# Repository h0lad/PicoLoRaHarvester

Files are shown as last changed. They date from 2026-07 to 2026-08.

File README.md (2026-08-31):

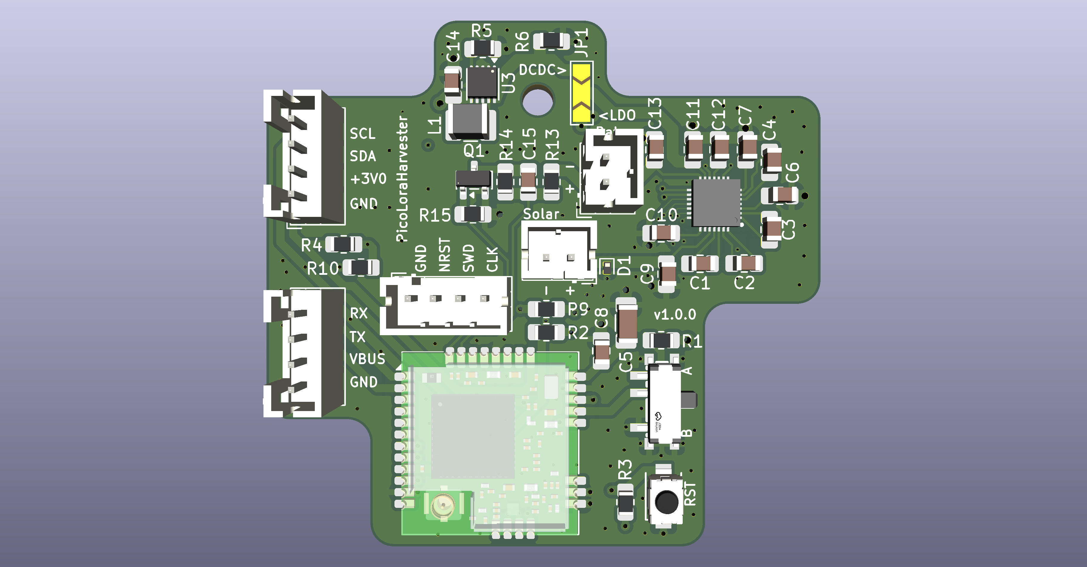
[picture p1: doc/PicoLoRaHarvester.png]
MeshtasticRouterNode


# PicoLoRaHarvester

## What is this thing?

This PCB integrates a [RAK3172 LoRa module](https://docs.rakwireless.com/Product-Categories/WisDuo/RAK3172-Module/Datasheet/) (STM32WLE5) with a [Nexperia NEH7100](https://assets.nexperia.com/documents/data-sheet/NEH7100.pdf) energy harvesting PMIC. 

Main target are solar-powered LoRa nodes that run unattended in off-grid locations.

The board is compatible to Meshcore and Mesthastic. But basically it's a nice platform for all kind of LoRa(WAN) applications.

Beware that both firmwares need Power Saving patches (Semtech RX duty cycle and uC deep sleep) due to the limited harvesting capability of the IC.

For get the basic device running you only have to populate the NEF7100 + Voltage Divider with Mosfet + RAK3172 + Switch + SWD. All others (FRAM/DCDC) is optional. This should make it by far the cheapest Meshcore repeater in the market.

## Features

* Energy harvesting via Nexperia NEH7100 PMIC: 15 μW to 100 mW input range, up to 95% efficiency
* Compatible to basically all all 1-cell energy storage: LiPo, LiFePo4, LTO, Supercaps, etc.
* Storage Type, OVP/UVP/etc. can be configured with solder bridges on the back
* With a soldering bridge you can either go for the internal Nexperia NEH7100 LDO (for low BOM) or use a TI TPS63900 Buck-Boost Converter
* USB bypass charging (VUSB) at up to 200 mA via the UART connector
* Battery (ADC_LIPO) voltage monitoring using a voltage divider, on/off switchable with a n-Mosfet
* I²C Infineon FRAM (FM24V10) on the back for data logging 

## Physical Outlines

| Dimension | Value |
|---|---|
| Width | 50.54 mm |
| Height | 45.50 mm |

Fits into this box: [Aliexpress, F-type, 63x58x35](https://de.aliexpress.com/item/1005005480970197.html).

Yes - the mounting hole is not symmetric. 

## Pinout

### Connectors

| Designator | Connector | Pins | Purpose |
|---|---|---|---|
| J1 | Pin header 1x06 (1.00 mm) | 1: GND, 2: +3V0, 3: SPI1 SS (PA4), 4: SPI1 CLK (PA5), 5: SPI1 MISO (PA6), 6: SPI1 MOSI (PA7) | SPI expansion bus (SPI1) |
| J2 | JST PH 2-pin | 1: VBUS, 2: GND | Solar panel input (feeds NEH7100 energy harvester) |
| J3 | JST PH 4-pin | 1: GND, 2: VUSB, 3: UART TX, 4: UART RX | UART + USB bypass charging (200 mA) |
| J4 | JST PH 2-pin | 1: VLIPO, 2: GND | LiPo battery |
| J5 | JST PH 4-pin | 1: GND, 2: +3V0, 3: I2C1 SDA, 4: I2C1 SCL | I²C expansion bus (I2C1) |
| J6 | JST PH 4-pin | 1: GND, 2: NRST, 3: SWD, 4: SWCLK | SWD debug/programming |

### RAK3172 Pin Mapping

| RAK3172 Pin | Function | Connected To |
|---|---|---|
| PA2 | UART2 TX | J3 pin 3 |
| PA3 | UART2 RX | J3 pin 4 |
| PA4 | SPI1 SS | J1 pin 3 |
| PA5 | SPI1 CLK | J1 pin 4 |
| PA6 | SPI1 MISO | J1 pin 5 |
| PA7 | SPI1 MOSI | J1 pin 6 |
| PA9 | I2C1 SCL | J5 pin 4, U4 (FM24V10) SCL |
| PA10 | I2C1 SDA | J5 pin 3, U4 (FM24V10) SDA |
| PA11 | I2C2 SDA | NEH7100 SDA (PMIC config bus) |
| PA12 | I2C2 SCL | NEH7100 SCL (PMIC config bus) |
| PA13 | SWDIO | J6 pin 3 |
| PA14 | SWCLK | J6 pin 4 |
| PB3 / A0 | GPIO out | EN_VOL_DIVIDER (Q1 n-MOSFET load switch for the ADC_LIPO divider) |
| PB4 / A1 | ADC | ADC_LIPO (battery voltage divider, R13/R14 + C15) |
| BOOT0 | Bootloader | SW1 (SSSS811101 slide switch) via R1 (10 kΩ) |
| NRST | Reset | SW2 (push button), J6 pin 2 |

### I²C Bus Allocation

| Bus | Pins | Purpose |
|-----|---|---|
| I2C1 | PA9 (SCL), PA10 (SDA) | J5 expansion connector for external sensors/peripherals + FM24V10 F-RAM (U4, on the back) for data logging |
| I2C2 | PA12 (SCL), PA11 (SDA) | NEH7100 PMIC telemetry and configuration |

Both I²C buses have on-board 10 kΩ pull-up resistors (R4/R10 for I2C1, R2/R9 for I2C2).

## Voltage Monitoring

| Net | Divider | Ratio | RAK3172 ADC Pin |
|-----|---|---|---|
| ADC_LIPO | R13 (390 kΩ) / R14 (1 MΩ) + C15 (100 nF) | ~0.72 | PB4 / A1 |

## FAQ

#### How much current can I expect from the NEH7100?

The NEH7100 has an input power range of 15 μW to 100 mW and efficiency up to 95% (per [datasheet](https://assets.nexperia.com/documents/data-sheet/NEH7100.pdf)).

The USB input (VUSB on J3 pin 2) bypasses the charge pump and can supply up to 200 mA directly for bench use or supplemental charging.

#### Why the NEH7100 instead of the TI BQ25570?

* Voltage thresholds (OVP, LVD, LDO) are set by hard-code pins or I²C registers. The BQ25570 programs them with external resistor dividers, which adds resistor tolerance to every threshold and a permanent leakage path across the battery.
* The charge current can be read back over I²C (I_MEASURED/I_RANGE registers). The BQ25570 has no digital interface.
* External circuit consists of capacitors only. The BQ25570 needs an inductor each for its boost charger and buck converter.
* The pinout groups the flying caps, I²C and power pins by side, so routing needs no crossovers and there are no switching inductor loops to keep tight.

## Hardware Verification

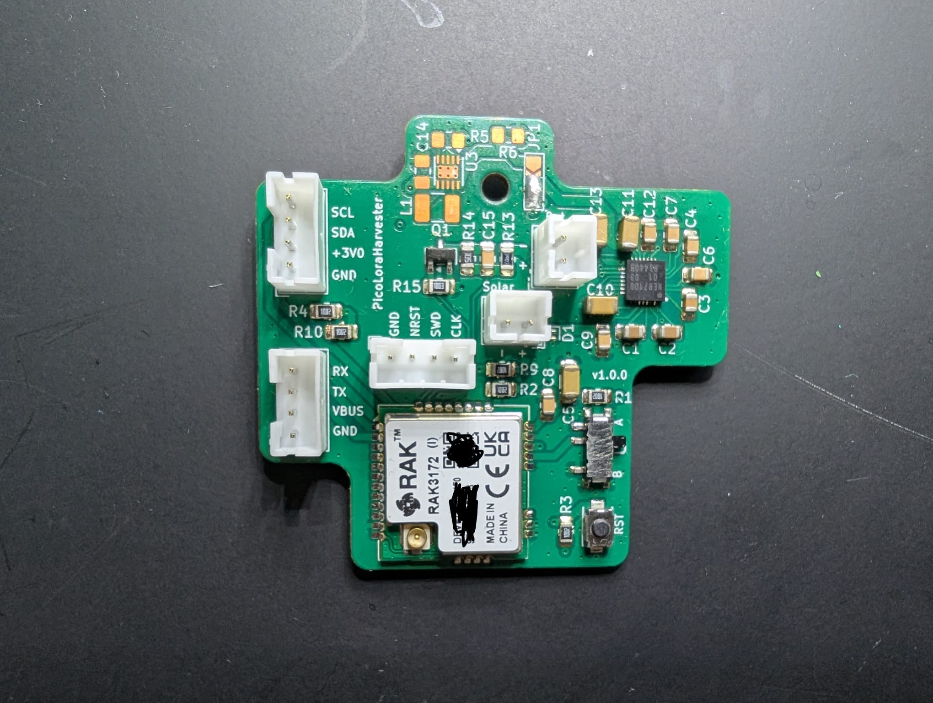
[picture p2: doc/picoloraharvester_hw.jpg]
PicoLoRaHarvester


✅ HC 00001 Configuration works

✅ Bat -> 3.0V via LDO

✅ Charging Bat via VIN

## License

CERN-OHL-S-2.0

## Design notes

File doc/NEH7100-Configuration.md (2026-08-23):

## NEH7100 without LDO/Buck → STM32WLE

This uses the wide voltage input range of the STM32WLE. It perfectly fits a LiFePO4.

LDO in bypass: `VLDO` follows `VBAT`.

| Chemistry | Climate | HC\[4:0\] | HC live (OVP / LVD / USB) | `0x00` | `0x01` | `0x05` |
|---|---|---|---|---|---|---|
| LiFePO4 | mountain | `11010` | 3.50 / 2.50 / 150 mA | `0x65` 2.80 / 3.50 | `0x87` | `0x00` |
| LiFePO4 | indoor | `11010` | 3.50 / 2.50 / 150 mA | `0x36` 2.50 / 3.60 | `0x87` | `0x01` |

## NEH7100 with a connected Buck-Boost (3.3 V) → STM32WLE

LDO in bypass: `VLDO` follows `VBAT`. STM32 runs from the converter.

This might be needed if you are either using Na-ion (which has a useable voltage range below 3.0V) or even with a LiPo if you need the full 3.3V for unlimited TX power of the LoRa module.

| Chemistry | Climate | HC\[4:0\] | HC live (OVP / LVD / USB) | `0x00` | `0x01` | `0x05` |
|---|---|---|---|---|---|---|
| LiPo | mountain | `10010` | 4.00 / 3.30 / 100 mA | `0xAA` 3.20 / 4.00 | `0x87` | `0x00` |
| LiPo | indoor | `10010` | 4.00 / 3.30 / 100 mA | `0x8B` 3.00 / 4.10 | `0x87` | `0x01` |
| Na-ion | mountain summer | `10010` | 4.00 / 3.30 / 100 mA | `0x08` 2.20 / 3.80 | `0x87` | `0x00` |
| Na-ion | mountain winter | `10010` | 4.00 / 3.30 / 100 mA | `0x07` 2.20 / 3.70 | `0x87` | `0x00` |
| Na-ion | indoor | `10010` | 4.00 / 3.30 / 100 mA | `0x09` 2.20 / 3.90 | `0x87` | `0x01` |

## NEH7100 with internal LDO → STM32WLE

LDO set to 3.0 V. STM32 runs from `VLDO`. The "budget" variant.

| Chemistry | Climate | HC\[4:0\] | HC live (OVP / LVD / USB) | `0x00` | `0x01` | `0x05` |
|---|---|---|---|---|---|---|
| LiPo | mountain | `00001` | 4.20 / 3.20 / 200 mA | `0xAA` 3.20 / 4.00 | `0x2F` | `0x00` |
| LiPo | indoor | `00001` | 4.20 / 3.20 / 200 mA | `0x8B` 3.00 / 4.10 | `0x2F` | `0x01` |

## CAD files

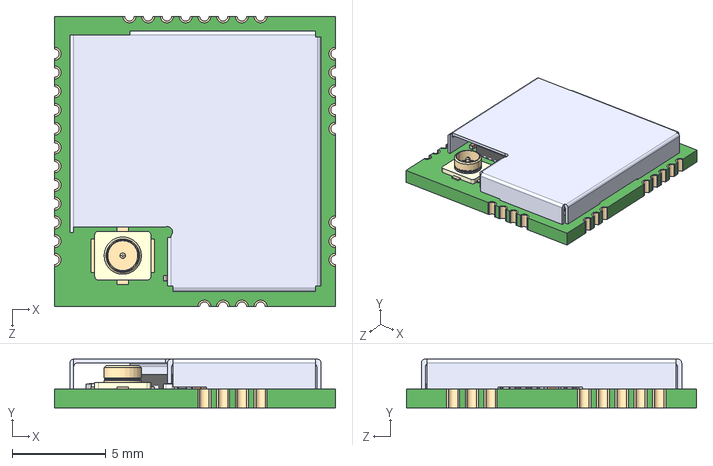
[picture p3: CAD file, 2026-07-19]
pcb/components/steps/RAK3172--3DModel-STEP-510211.step
15.0 x 2.60 x 15.5 mm

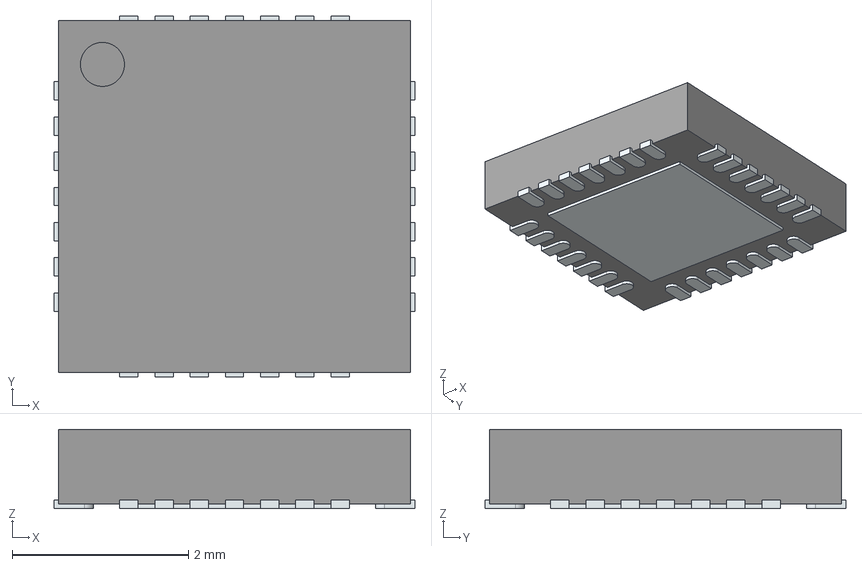
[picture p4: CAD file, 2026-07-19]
pcb/components/steps/NEH7100BUHP.stp
4.10 x 4.10 x 0.9 mm
ThermalPin
PinsArrayLR
PinsArrayTB

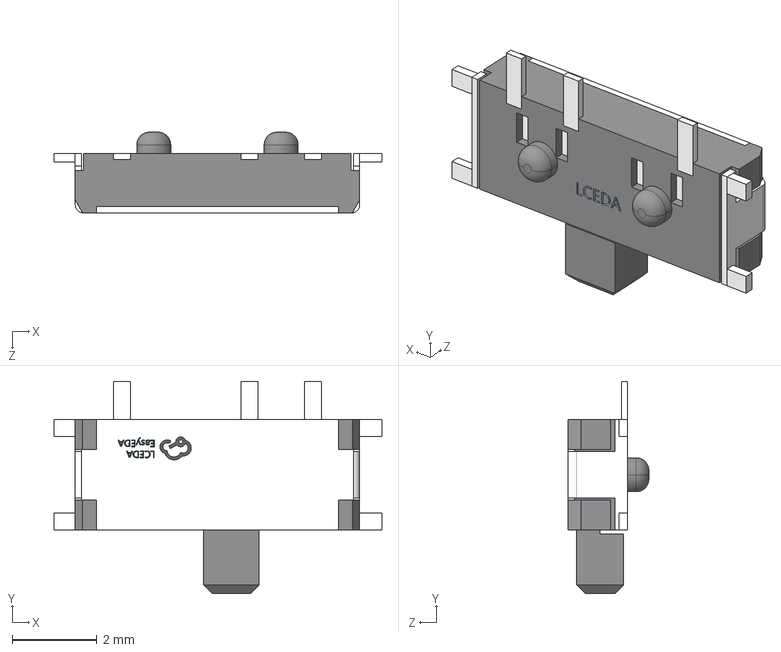
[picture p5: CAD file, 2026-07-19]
pcb/components/steps/SW-TH_SSSS811101.step
7.72 x 5.00 x 1.90 mm

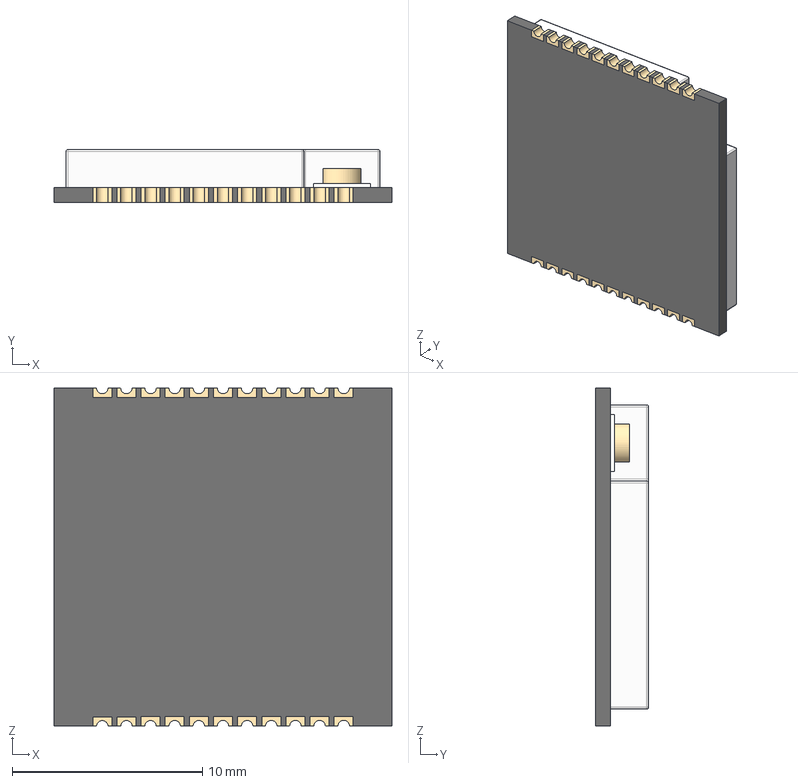
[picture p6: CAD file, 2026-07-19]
pcb/components/steps/heltecht62.step
17.8 x 2.80 x 17.8 mm

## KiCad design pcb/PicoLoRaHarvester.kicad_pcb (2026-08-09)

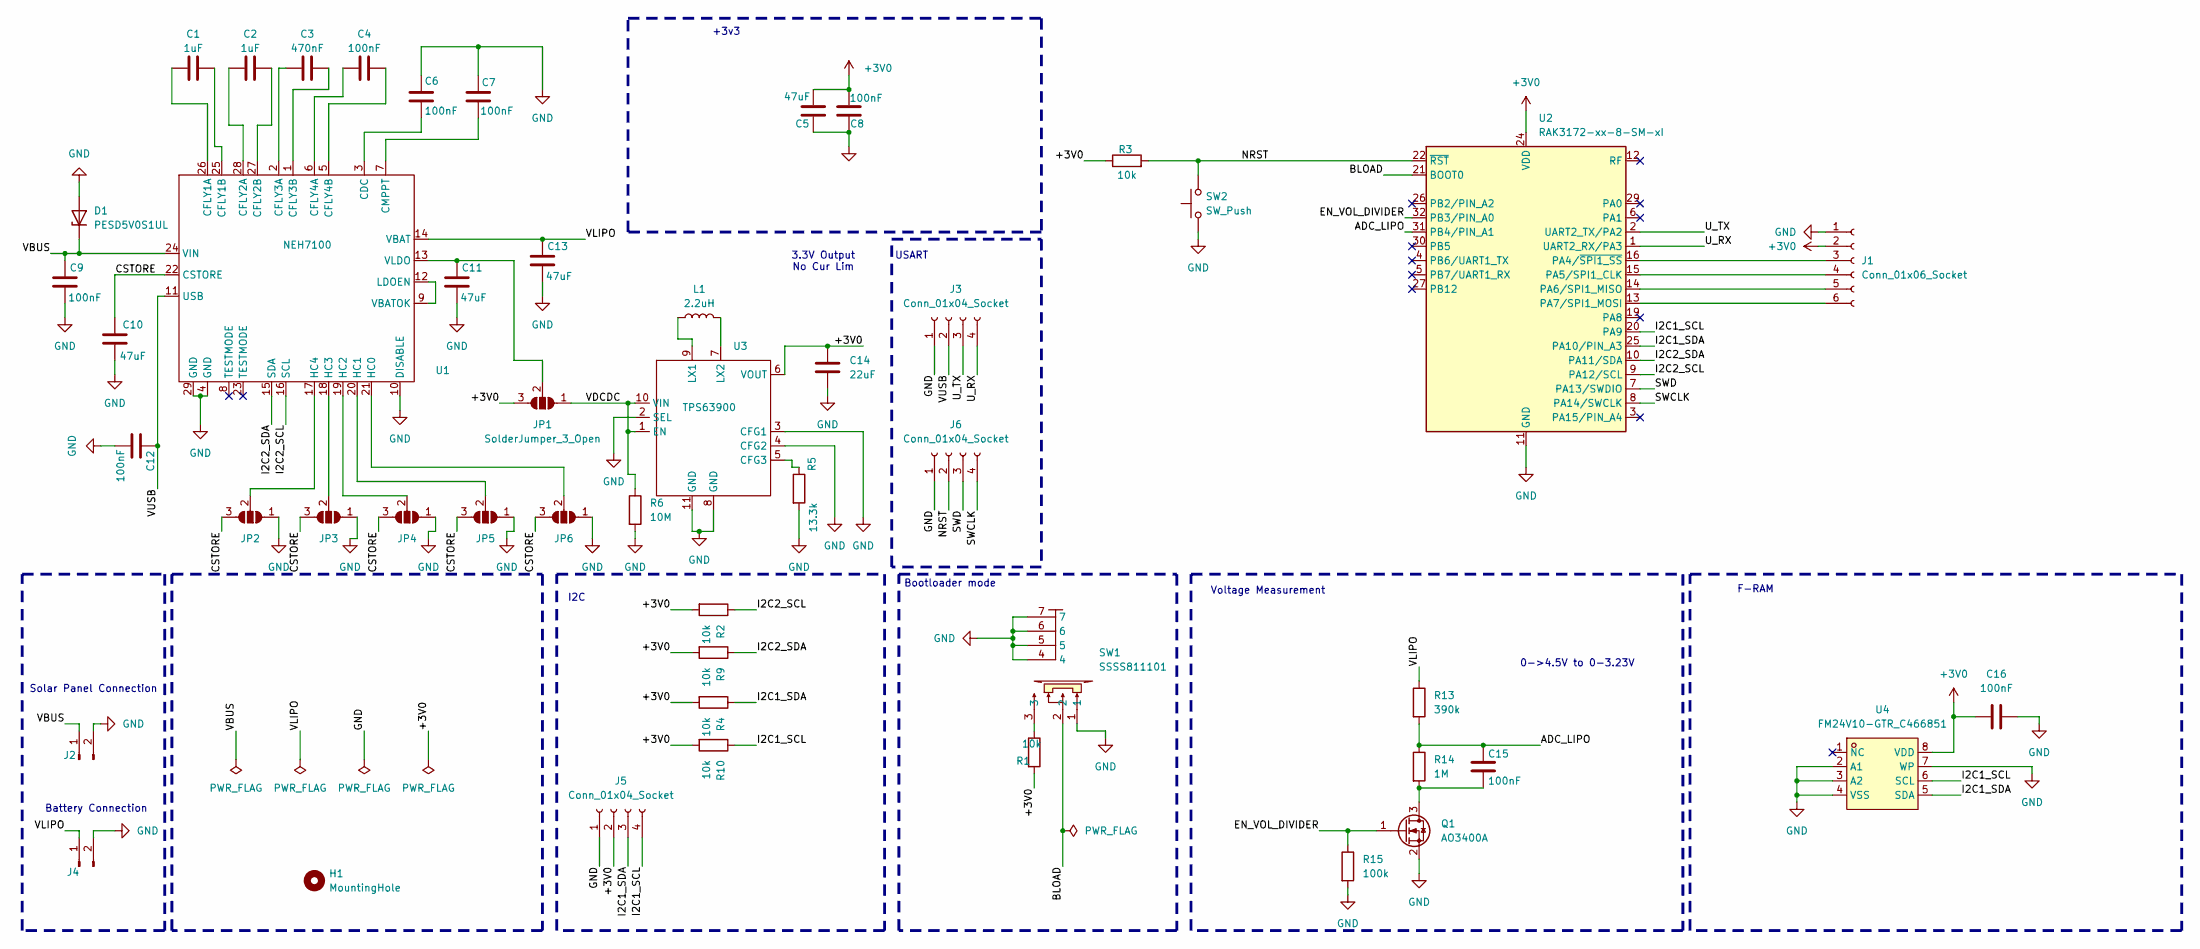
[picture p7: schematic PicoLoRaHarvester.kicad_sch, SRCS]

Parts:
C1, C2: 1uF; C_0805_2012Metric_Pad1.18x1.45mm_HandSolder
C3: 470nF; C_0805_2012Metric_Pad1.18x1.45mm_HandSolder
C4, C6, C7, C8, C9, C12, C15, C16: 100nF; C_0805_2012Metric_Pad1.18x1.45mm_HandSolder
C5: 47uF; C_1206_3216Metric_Pad1.33x1.80mm_HandSolder
C10, C11, C13: 47uF; C_0805_2012Metric_Pad1.18x1.45mm_HandSolder
C14: 22uF; C_0805_2012Metric_Pad1.18x1.45mm_HandSolder
D1: PESD5V0S1UL; D_SOD-882
H1: MountingHole; MountingHole_2.7mm_M2.5_ISO7380
J1: Conn_01x06_Socket; PinHeader_1x06_P1.00mm_Vertical_SMD_Pin1Left
J2: Conn_01x02_Socket; JST_PH_B2B-PH-K_1x02_P2.00mm_Vertical
J3, J5, J6: Conn_01x04_Socket; JST_PH_B4B-PH-K_1x04_P2.00mm_Vertical
J4: Conn_01x02_Pin; JST_PH_B2B-PH-K_1x02_P2.00mm_Vertical
JP1: SolderJumper_3_Open; SolderJumper-3_P2.0mm_Open_TrianglePad1.0x1.5mm_NumberLabels
JP2, JP3, JP4, JP5, JP6: SolderJumper_3_Open; SolderJumper-3_P1.3mm_Open_RoundedPad1.0x1.5mm
L1: 2.2uH; L_1210_3225Metric_Pad1.42x2.65mm_HandSolder
Q1: AO3400A; SOT-23
R1, R2, R3, R4, R9, R10: 10k; R_0805_2012Metric_Pad1.20x1.40mm_HandSolder
R5: 13.3k; R_0805_2012Metric_Pad1.20x1.40mm_HandSolder
R6: 10M; R_0805_2012Metric_Pad1.20x1.40mm_HandSolder
R13: 390k; R_0805_2012Metric_Pad1.20x1.40mm_HandSolder
R14: 1M; R_0805_2012Metric_Pad1.20x1.40mm_HandSolder
R15: 100k; R_0805_2012Metric_Pad1.20x1.40mm_HandSolder
SW1: SSSS811101; SW-SMD_SSSS811101; LCSC Part C109335
SW2: SW_Push; SW-SMD_L3.9-W3.0-P4.45
U1: NEH7100; QFN40P400X400X90-29N-D
U2: RAK3172-xx-8-SM-xI; RAK3172
U3: TPS63900; WSON-10-1EP_2.5x2.5mm_P0.5mm_EP1.2x2mm_ThermalVias
U4: FM24V10-GTR_C466851; SOIC-8_5.3x5.3mm_P1.27mm; LCSC Part C466851

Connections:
+3V0: C5.2, C8.2, C14.2, C16.1, J1.2, J5.2, JP1.3 (B), R1.2, R2.2, R3.1, R4.2, R9.2, R10.2, U2.24 (VDD), U3.6 (VOUT), U4.8 (VDD)
/ADC_LIPO: C15.1, R13.2, R14.1, U2.31 (PB4/PIN_A1)
/BLOAD: SW1.2, U2.21 (BOOT0)
/CSTORE: C10.1, JP2.3 (B), JP3.3 (B), JP4.3 (B), JP5.3 (B), JP6.3 (B), U1.22 (CSTORE)
/EN_VOL_DIVIDER: Q1.1 (G), R15.1, U2.32 (PB3/PIN_A0)
/I2C1_SCL: J5.4, R10.1, U2.20 (PA9), U4.6 (SCL)
/I2C1_SDA: J5.3, R4.1, U2.25 (PA10/PIN_A3), U4.5 (SDA)
/I2C2_SCL: R2.1, U1.16 (SCL), U2.9 (PA12/SCL)
/I2C2_SDA: R9.1, U1.15 (SDA), U2.10 (PA11/SDA)
/NRST: J6.2, R3.2, SW2.2, U2.22 (~RST)
/SWCLK: J6.4, U2.8 (PA14/SWCLK)
/SWD: J6.3, U2.7 (PA13/SWDIO)
/U_RX: J3.4, U2.1 (UART2_RX/PA3)
/U_TX: J3.3, U2.2 (UART2_TX/PA2)
/VBUS: C9.2, D1.1 (K), J2.1, U1.24 (VIN)
/VDCDC: JP1.1 (A), R6.1, U3.1 (EN), U3.10 (VIN)
/VLIPO: C13.2, J4.1, R13.1, U1.14 (VBAT)
/VUSB: C12.2, J3.2, U1.11 (USB)
GND: C5.1, C6.1, C7.1, C8.1, C9.1, C10.2, C11.1, C12.1, C13.1, C14.1, C16.2, D1.2 (A), J1.1, J2.2, J3.1, J4.2, J5.1, J6.1, JP2.1 (A), JP3.1 (A), JP4.1 (A), JP5.1 (A), JP6.1 (A), Q1.2 (S), R5.2, R6.2, R15.2, SW1.1, SW1.4, SW1.5, SW1.6, SW1.7, SW2.1, U1.4 (GND), U1.10 (DISABLE), U1.29 (GND), U2.11 (GND), U2.17 (GND), U2.18 (GND), U2.23 (GND), U2.28 (GND), U3.2 (SEL), U3.3 (CFG1), U3.4 (CFG2), U3.8 (GND), U3.11 (GND), U4.2 (A1), U4.3 (A2), U4.4 (VSS), U4.7 (WP)
unnamed: J1.3, U2.16 (PA4/~SPI1_SS)
unnamed: J1.4, U2.15 (PA5/SPI1_CLK)
unnamed: J1.5, U2.14 (PA6/SPI1_MISO)
unnamed: J1.6, U2.13 (PA7/SPI1_MOSI)
unnamed: C11.2, JP1.2 (C), U1.13 (VLDO)
unnamed: JP2.2 (C), U1.17 (HC4)
unnamed: JP3.2 (C), U1.18 (HC3)
unnamed: JP4.2 (C), U1.19 (HC2)
unnamed: JP5.2 (C), U1.20 (HC1)
unnamed: JP6.2 (C), U1.21 (HC0)
unnamed: C15.2, Q1.3 (D), R14.2
unnamed: R1.1, SW1.3
unnamed: C6.2, U1.3 (CDC)
unnamed: C1.1, U1.26 (CFLY1A)
unnamed: C1.2, U1.25 (CFLY1B)
unnamed: C2.1, U1.28 (CFLY2A)
unnamed: C2.2, U1.27 (CFLY2B)
unnamed: C3.1, U1.2 (CFLY3A)
unnamed: C3.2, U1.1 (CFLY3B)
unnamed: C4.1, U1.6 (CFLY4A)
unnamed: C4.2, U1.5 (CFLY4B)
unnamed: C7.2, U1.7 (CMPPT)
unnamed: U1.9 (VBATOK), U1.12 (LDOEN)
unnamed: R5.1, U3.5 (CFG3)
unnamed: L1.1, U3.9 (LX1)
unnamed: L1.2, U3.7 (LX2)

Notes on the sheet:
Bootloader mode
F-RAM
USART
Voltage Measurement
+3v3
Solar Panel Connection
I2C
Battery Connection
3.3V Output No Cur Lim
0->4.5V to 0-3.23V

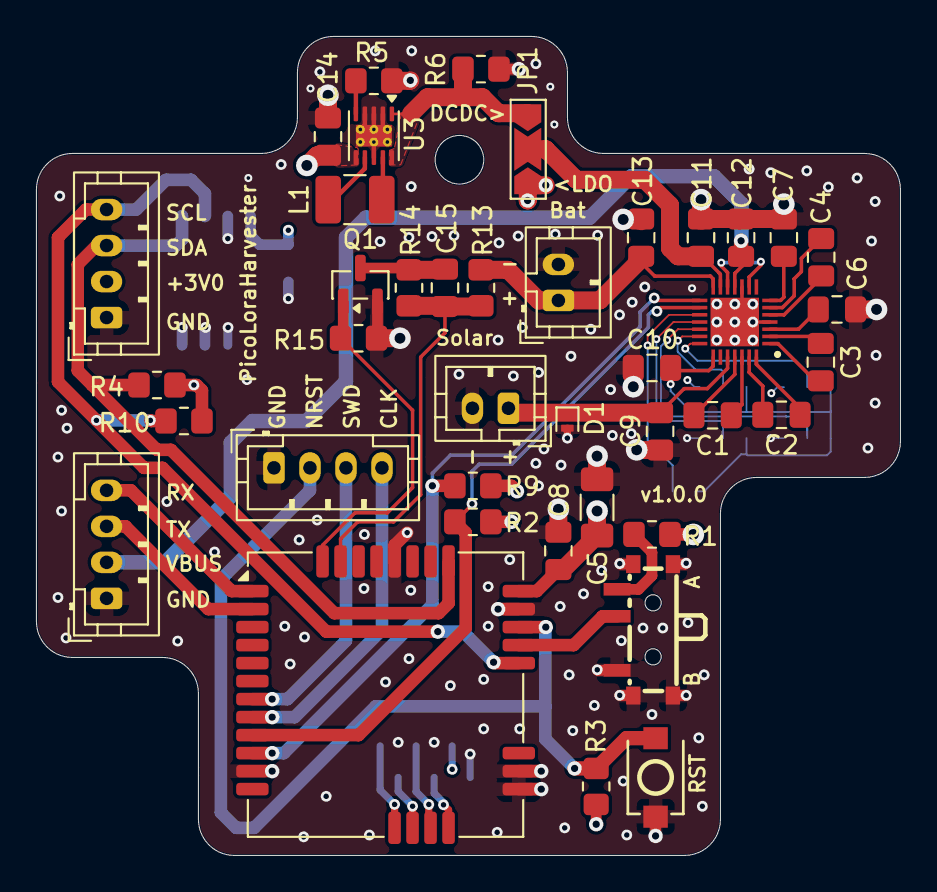
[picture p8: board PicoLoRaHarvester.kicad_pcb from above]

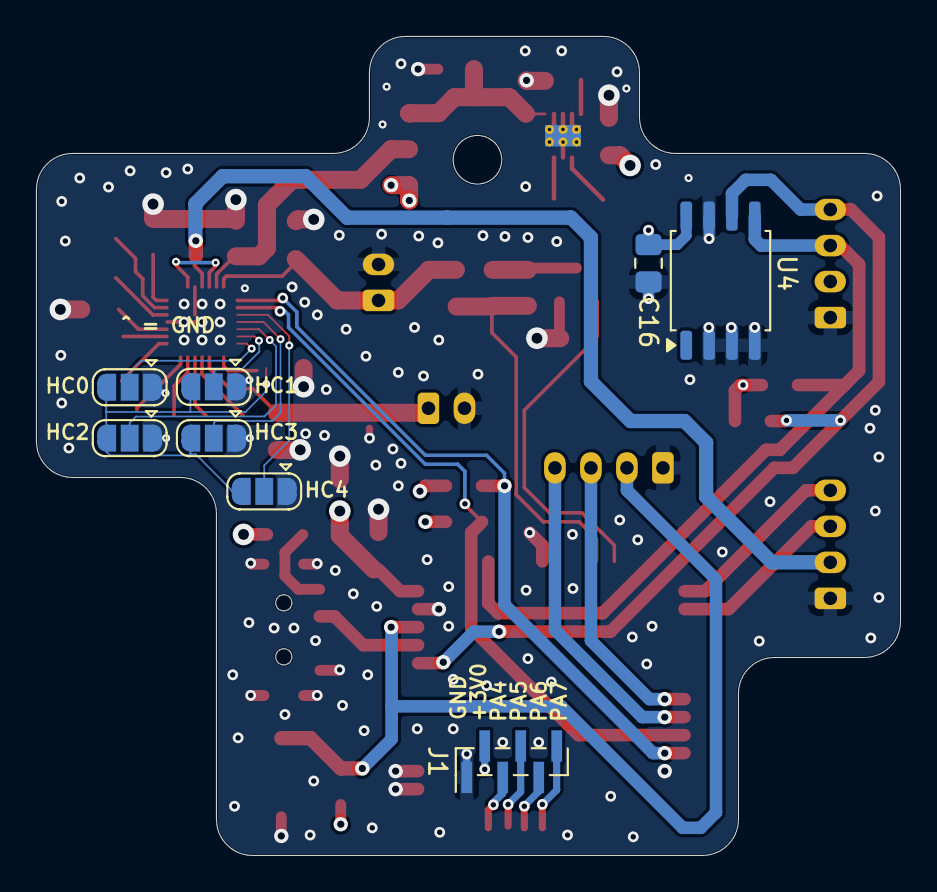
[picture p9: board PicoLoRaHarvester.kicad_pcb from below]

Board: 4 copper layers, 48.0 x 45.5 mm, 49 parts (8 on the bottom side), 45 nets.

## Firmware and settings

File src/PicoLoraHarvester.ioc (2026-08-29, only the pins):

Mcu.UserName=STM32WLE5CCUx
PA10.GPIO_Label=I2C1_SDA_EXT
PA10.Signal=I2C1_SDA
PA11.GPIO_Label=I2C2_SDA_PMIC
PA11.Signal=I2C2_SDA
PA12.GPIO_Label=I2C2_SCL_PMIC
PA12.Signal=I2C2_SCL
PA13.Signal=DEBUG_JTMS-SWDIO
PA14.Signal=DEBUG_JTCK-SWCLK
PA2.Signal=USART2_TX
PA3.Signal=USART2_RX
PA4.GPIO_Label=SPI1_CS
PA4.Signal=GPIO_Output
PA5.Signal=SPI1_SCK
PA6.Signal=SPI1_MISO
PA7.Signal=SPI1_MOSI
PA9.GPIO_Label=I2C1_SCL_EXT
PA9.Signal=I2C1_SCL
PB3.GPIO_Label=EN_VOL_DIVIDER
PB3.Signal=GPIO_Output
PB4.GPIO_Label=ADC_IN3_BAT
PB4.Signal=ADC_IN3

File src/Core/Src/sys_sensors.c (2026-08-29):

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

/* Includes ------------------------------------------------------------------*/
#include "stdint.h"
#include "platform.h"
#include "sys_conf.h"
#include "sys_sensors.h"
#if defined (SENSOR_ENABLED) && (SENSOR_ENABLED == 0)
#include "adc_if.h"
#endif /* SENSOR_ENABLED */

/* USER CODE BEGIN Includes */
#if defined (SENSOR_ENABLED) && (SENSOR_ENABLED == 1)
#if defined (X_NUCLEO_IKS01A2)
#warning "IKS drivers are today available for several families but not stm32WL"
#warning "up to the user adapt IKS low layer to map it on WL board driver"
#warning "this code would work only if user provide necessary IKS and BSP layers"
#include "iks01a2_env_sensors.h"
#elif defined (X_NUCLEO_IKS01A3)

/*
## How to add IKS01A3 to STM32CubeWL
   Note that LoRaWAN_End_Node Example is used as an example for steps below.
 1. Open the LoRaWAN_End_Node CubeMX project by double-clicking on the LoRaWAN_End_Node.ioc under "STM32Cube_FW_WL_V1.x.x\Projects\NUCLEO-WL55JC\Applications\LoRaWAN\LoRaWAN_End_Node"
 2. From the CubeMX project, click on "Software Packs"->"Manage Software Packs" to open the Embedded Software Packages Manager. Then, click on the "STMicroelectronics" tab, expand the X-CUBE-MEMS1, check the latest version of this pack (i.e. 9.0.0), and install. Then, close the Embedded Software Packages Manager.
 3. From the CubeMX project, click on "Software Packs"->"Select Components" to open the Software Packs Component Selector, expand the X-CUBE-MEMS1 pack and select the "Board Extension IKS01A3" component by checking the respective box, and click OK.
 4. From the CubeMX project, expand the "Connectivity" category and enable I2C2 on pins PA11 (I2C2_SDA) and PA12 (I2C2_SCK).
 5. From the CubeMX project, expand the "Software Packs" category and enable the "Board Extension IKS01A3" by checking the box, and choose I2C2 under the "Found Solutions" menu.
 6. From the CubeMX project, click the "Project Manager" section
    - From the "Project Settings" section, select your Toolchain/IDE of choice (if CubeIDE, uncheck the "Generator Under Root" option).
    - From the "Code Generator" section, select "Copy only the necessary library files".
 7. Click "GENERATE CODE" to generate the code project with the MEMS drivers integrated.
 8. From the code project, find and open the sys_conf.h and make the following edits
    - Set the #define SENSOR_ENABLED to 1
    - Set the #define LOW_POWER_DISABLE to 1 to prevent the device from entering low power mode. This is needed, since the I2C2 requires handling when exiting low power modes, so to prevent issues, best is to disable low power mode, however, if low power mode is desired, you'll have to re-initialize the I2C2 from PWR_ExitStopMode() in stm32_lpm_if.c, so you can just call HAL_I2C_Init() from there.
 9. From the code project, find and open lora_app.h, and uncomment the following line
    #define CAYENNE_LPP
 10. From the code project properties, add X_NUCLEO_IKS01A3 Pre-processor Defined symbol.
 11. Save all changes and build project
 12. Connect the X-NUCLEO-IKS01A3 expansion board on the NUCLEO-WL55JC1
 13. Load and run the code
*/
#warning "IKS drivers are today available for several families but not stm32WL, follow steps defined in sys_sensors.c"
#include "iks01a3_env_sensors.h"
#else  /* not X_IKS01xx */
#error "user to include its sensor drivers"
#endif  /* X_NUCLEO_IKS01xx */
#elif !defined (SENSOR_ENABLED)
#error SENSOR_ENABLED not defined
#endif  /* SENSOR_ENABLED */
/* USER CODE END Includes */

/* External variables ---------------------------------------------------------*/

/* USER CODE BEGIN PD */
#define STSOP_LATTITUDE           ((float) 43.618622 )  /*!< default latitude position */
#define STSOP_LONGITUDE           ((float) 7.051415  )  /*!< default longitude position */
#define MAX_GPS_POS               ((int32_t) 8388607 )  /*!< 2^23 - 1 */
#define HUMIDITY_DEFAULT_VAL      50.0f                 /*!< default humidity */
#define TEMPERATURE_DEFAULT_VAL   18.0f                 /*!< default temperature */
#define PRESSURE_DEFAULT_VAL      1000.0f               /*!< default pressure */
/* USER CODE END PD */


/* USER CODE BEGIN PV */
#if defined (SENSOR_ENABLED) && (SENSOR_ENABLED == 1)
#if defined (X_NUCLEO_IKS01A2)
#warning "IKS drivers are today available for several families but not stm32WL"
#warning "up to the user adapt IKS low layer to map it on WL board driver"
#warning "this code would work only if user provide necessary IKS and BSP layers"
IKS01A2_ENV_SENSOR_Capabilities_t EnvCapabilities;
#elif defined (X_NUCLEO_IKS01A3)
IKS01A3_ENV_SENSOR_Capabilities_t EnvCapabilities;
#else  /* not X_IKS01Ax */
#error "user to include its sensor drivers"
#endif  /* X_NUCLEO_IKS01 */
#elif !defined (SENSOR_ENABLED)
#error SENSOR_ENABLED not defined
#endif  /* SENSOR_ENABLED */
/* USER CODE END PV */

/* Exported functions --------------------------------------------------------*/
int32_t EnvSensors_Read(sensor_t *sensor_data)
{
  /* USER CODE BEGIN EnvSensors_Read */
  float HUMIDITY_Value = HUMIDITY_DEFAULT_VAL;
  float TEMPERATURE_Value = TEMPERATURE_DEFAULT_VAL;
  float PRESSURE_Value = PRESSURE_DEFAULT_VAL;

#if defined (SENSOR_ENABLED) && (SENSOR_ENABLED == 1)
#if (USE_IKS01A2_ENV_SENSOR_HTS221_0 == 1)
  IKS01A2_ENV_SENSOR_GetValue(HTS221_0, ENV_HUMIDITY, &HUMIDITY_Value);
  IKS01A2_ENV_SENSOR_GetValue(HTS221_0, ENV_TEMPERATURE, &TEMPERATURE_Value);
#endif /* USE_IKS01A2_ENV_SENSOR_HTS221_0 */
#if (USE_IKS01A2_ENV_SENSOR_LPS22HB_0 == 1)
  IKS01A2_ENV_SENSOR_GetValue(LPS22HB_0, ENV_PRESSURE, &PRESSURE_Value);
  IKS01A2_ENV_SENSOR_GetValue(LPS22HB_0, ENV_TEMPERATURE, &TEMPERATURE_Value);
#endif /* USE_IKS01A2_ENV_SENSOR_LPS22HB_0 */
#if (USE_IKS01A3_ENV_SENSOR_HTS221_0 == 1)
  IKS01A3_ENV_SENSOR_GetValue(IKS01A3_HTS221_0, ENV_HUMIDITY, &HUMIDITY_Value);
  IKS01A3_ENV_SENSOR_GetValue(IKS01A3_HTS221_0, ENV_TEMPERATURE, &TEMPERATURE_Value);
#endif /* USE_IKS01A3_ENV_SENSOR_HTS221_0 */
#if (USE_IKS01A3_ENV_SENSOR_LPS22HH_0 == 1)
  IKS01A3_ENV_SENSOR_GetValue(IKS01A3_LPS22HH_0, ENV_PRESSURE, &PRESSURE_Value);
  IKS01A3_ENV_SENSOR_GetValue(IKS01A3_LPS22HH_0, ENV_TEMPERATURE, &TEMPERATURE_Value);
#endif /* USE_IKS01A3_ENV_SENSOR_LPS22HH_0 */
#else
  TEMPERATURE_Value = (sys_get_temperature_level() >> 8);
#endif  /* SENSOR_ENABLED */

  sensor_data->humidity    = HUMIDITY_Value;
  sensor_data->temperature = TEMPERATURE_Value;
  sensor_data->pressure    = PRESSURE_Value;

  sensor_data->latitude  = (int32_t)((STSOP_LATTITUDE  * MAX_GPS_POS) / 90);
  sensor_data->longitude = (int32_t)((STSOP_LONGITUDE  * MAX_GPS_POS) / 180);

  return 0;
  /* USER CODE END EnvSensors_Read */
}

int32_t EnvSensors_Init(void)
{
  int32_t ret = 0;
  /* USER CODE BEGIN EnvSensors_Init */
#if defined (SENSOR_ENABLED) && (SENSOR_ENABLED == 1)
  /* Init */
#if (USE_IKS01A2_ENV_SENSOR_HTS221_0 == 1)
  ret = IKS01A2_ENV_SENSOR_Init(HTS221_0, ENV_TEMPERATURE | ENV_HUMIDITY);
  if (ret != BSP_ERROR_NONE)
  {
    Error_Handler();
  }
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

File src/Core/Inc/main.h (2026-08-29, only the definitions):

#define RTC_N_PREDIV_S 10
#define RTC_PREDIV_S ((1<<RTC_N_PREDIV_S)-1)
#define RTC_PREDIV_A ((1<<(15-RTC_N_PREDIV_S))-1)
#define EN_VOL_DIVIDER_Pin GPIO_PIN_3
#define EN_VOL_DIVIDER_GPIO_Port GPIOB
#define ADC_IN3_BAT_Pin GPIO_PIN_4
#define ADC_IN3_BAT_GPIO_Port GPIOB
#define SPI1_CS_Pin GPIO_PIN_4
#define SPI1_CS_GPIO_Port GPIOA
#define I2C1_SCL_EXT_Pin GPIO_PIN_9
#define I2C1_SCL_EXT_GPIO_Port GPIOA
#define I2C1_SDA_EXT_Pin GPIO_PIN_10
#define I2C1_SDA_EXT_GPIO_Port GPIOA
#define I2C2_SDA_PMIC_Pin GPIO_PIN_11
#define I2C2_SDA_PMIC_GPIO_Port GPIOA
#define I2C2_SCL_PMIC_Pin GPIO_PIN_12
#define I2C2_SCL_PMIC_GPIO_Port GPIOA

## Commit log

2026-07-19 Clean export from internal git
    [NEH7100BUHP.stp, PicoLoRaHarvester.kicad_pcb, PicoLoRaHarvester.kicad_sch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]
2026-07-19 README: add information regarding the mounting hole
2026-08-01 pcb, sch: add C to VUSB, reroute some traces to get ease component soldering later
    [PicoLoRaHarvester.kicad_pcb, PicoLoRaHarvester.kicad_sch]
2026-08-02 pcb, sch: expose SPI to the back of the PCB
    [PicoLoRaHarvester.kicad_pcb, PicoLoRaHarvester.kicad_sch]
2026-08-02 pcb, sch: add protection TVS to VIN to kill transients
    [PicoLoRaHarvester.kicad_pcb, PicoLoRaHarvester.kicad_sch]
2026-08-06 pcb, sch: remove voltage divider for VIN, add n-mosfet for switching the voltage divider VBAT on and off
    [PicoLoRaHarvester.kicad_pcb, PicoLoRaHarvester.kicad_sch]
2026-08-06 pcb, sch: add option to either go directly for 3.0V from the NEF9100 LDO or use the TPS63900
    [PicoLoRaHarvester.kicad_pcb, PicoLoRaHarvester.kicad_sch]
2026-08-06 pcb, sch: improve traces
    [PicoLoRaHarvester.kicad_pcb, PicoLoRaHarvester.kicad_sch]
2026-08-07 README: our voltage divider is now switchable!
2026-08-07 pcb, sch: make HC[0-4] pins configurable on the back
    [PicoLoRaHarvester.kicad_pcb, PicoLoRaHarvester.kicad_sch]
2026-08-07 pcb, sch: add a very weak pull-down to the input of the TPS63900 - otherwise EN can up float which is strictly forbidden
    [PicoLoRaHarvester.kicad_pcb, PicoLoRaHarvester.kicad_sch]
2026-08-08 README: soldering bridges and gramar
2026-08-08 pcb: small non-functional board improvements
    [PicoLoRaHarvester.kicad_pcb]
2026-08-08 pcb, sch: add I2C FRAM to the back
    [PicoLoRaHarvester.kicad_pcb, PicoLoRaHarvester.kicad_sch]
2026-08-08 pcb: add name+version of the pcb to silk print
    [PicoLoRaHarvester.kicad_pcb]
2026-08-08 pcb: mounting hole clearance
    [PicoLoRaHarvester.kicad_pcb]
2026-08-08 pcb, sch: add pin configuration<
    [PicoLoRaHarvester.kicad_sch]
2026-08-08 pcb, sch: remove a stray via and increase VDCDC pull-down to 10M
    [PicoLoRaHarvester.kicad_pcb, PicoLoRaHarvester.kicad_sch]
2026-08-09 pcb, sch: add silk to show where the LDO bridge is
    [PicoLoRaHarvester.kicad_pcb]
2026-08-09 pcb: improve silk print
    [PicoLoRaHarvester.kicad_pcb]
2026-08-31 src: remove some left-overs from adapting a Zephyr driver style

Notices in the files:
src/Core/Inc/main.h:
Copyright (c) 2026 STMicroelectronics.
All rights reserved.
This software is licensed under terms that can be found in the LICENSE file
